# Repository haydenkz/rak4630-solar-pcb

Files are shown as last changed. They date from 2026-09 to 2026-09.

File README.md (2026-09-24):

# rak4630-solar-pcb

Solar-powered MeshCore node PCB built around the **RAK4630-8-SM-I** (nRF52840 + SX1262 LoRa) module.

## Features
- RAK4630-8-SM-I LoRa / MCU module
- Dual-input Li-ion charging (USB-C and solar) via SGM41513 with power-path management
- SMT 18650 battery holder (MYOUNG BH-18650-B1BA002, LCSC C2988620) with NTC temperature sensing
- 3.3 V LDO rail (XC6206P332)
- Hardware low-voltage cutoff (MCP65R41 + TPS22917): switches the node off below ~3.30 V battery and back on above ~3.73 V; no firmware involvement. USB power always overrides it (D3), so the RAK can be flashed over USB with no cell or a flat one. JP1 bypasses it for bench use without USB or a cell.
- SWD programming / test points

## Files
| File | Description |
|---|---|
| `meshcore-solar.kicad_pro` | KiCad project |
| `meshcore-solar.kicad_sch` | Schematic |
| `meshcore-solar.kicad_pcb` | PCB layout |
| `meshcore-solar.pretty/`, `meshcore-solar.3dshapes/` | Project-local footprint (18650 holder) and 3D models |

## Requirements
- KiCad 10 (file format `generator_version 10.0`)
- Symbols and footprints are embedded in the design files. The battery holder footprint and 3D model live in the project library (`meshcore-solar.pretty`, `meshcore-solar.3dshapes`).

## Notes
- Solar panel connects to the PH2.0 `SOLAR IN` connector (P1) → SGM41513 `VAC`.
- No MPPT; the solar input feeds the charger's input-regulation loop directly.

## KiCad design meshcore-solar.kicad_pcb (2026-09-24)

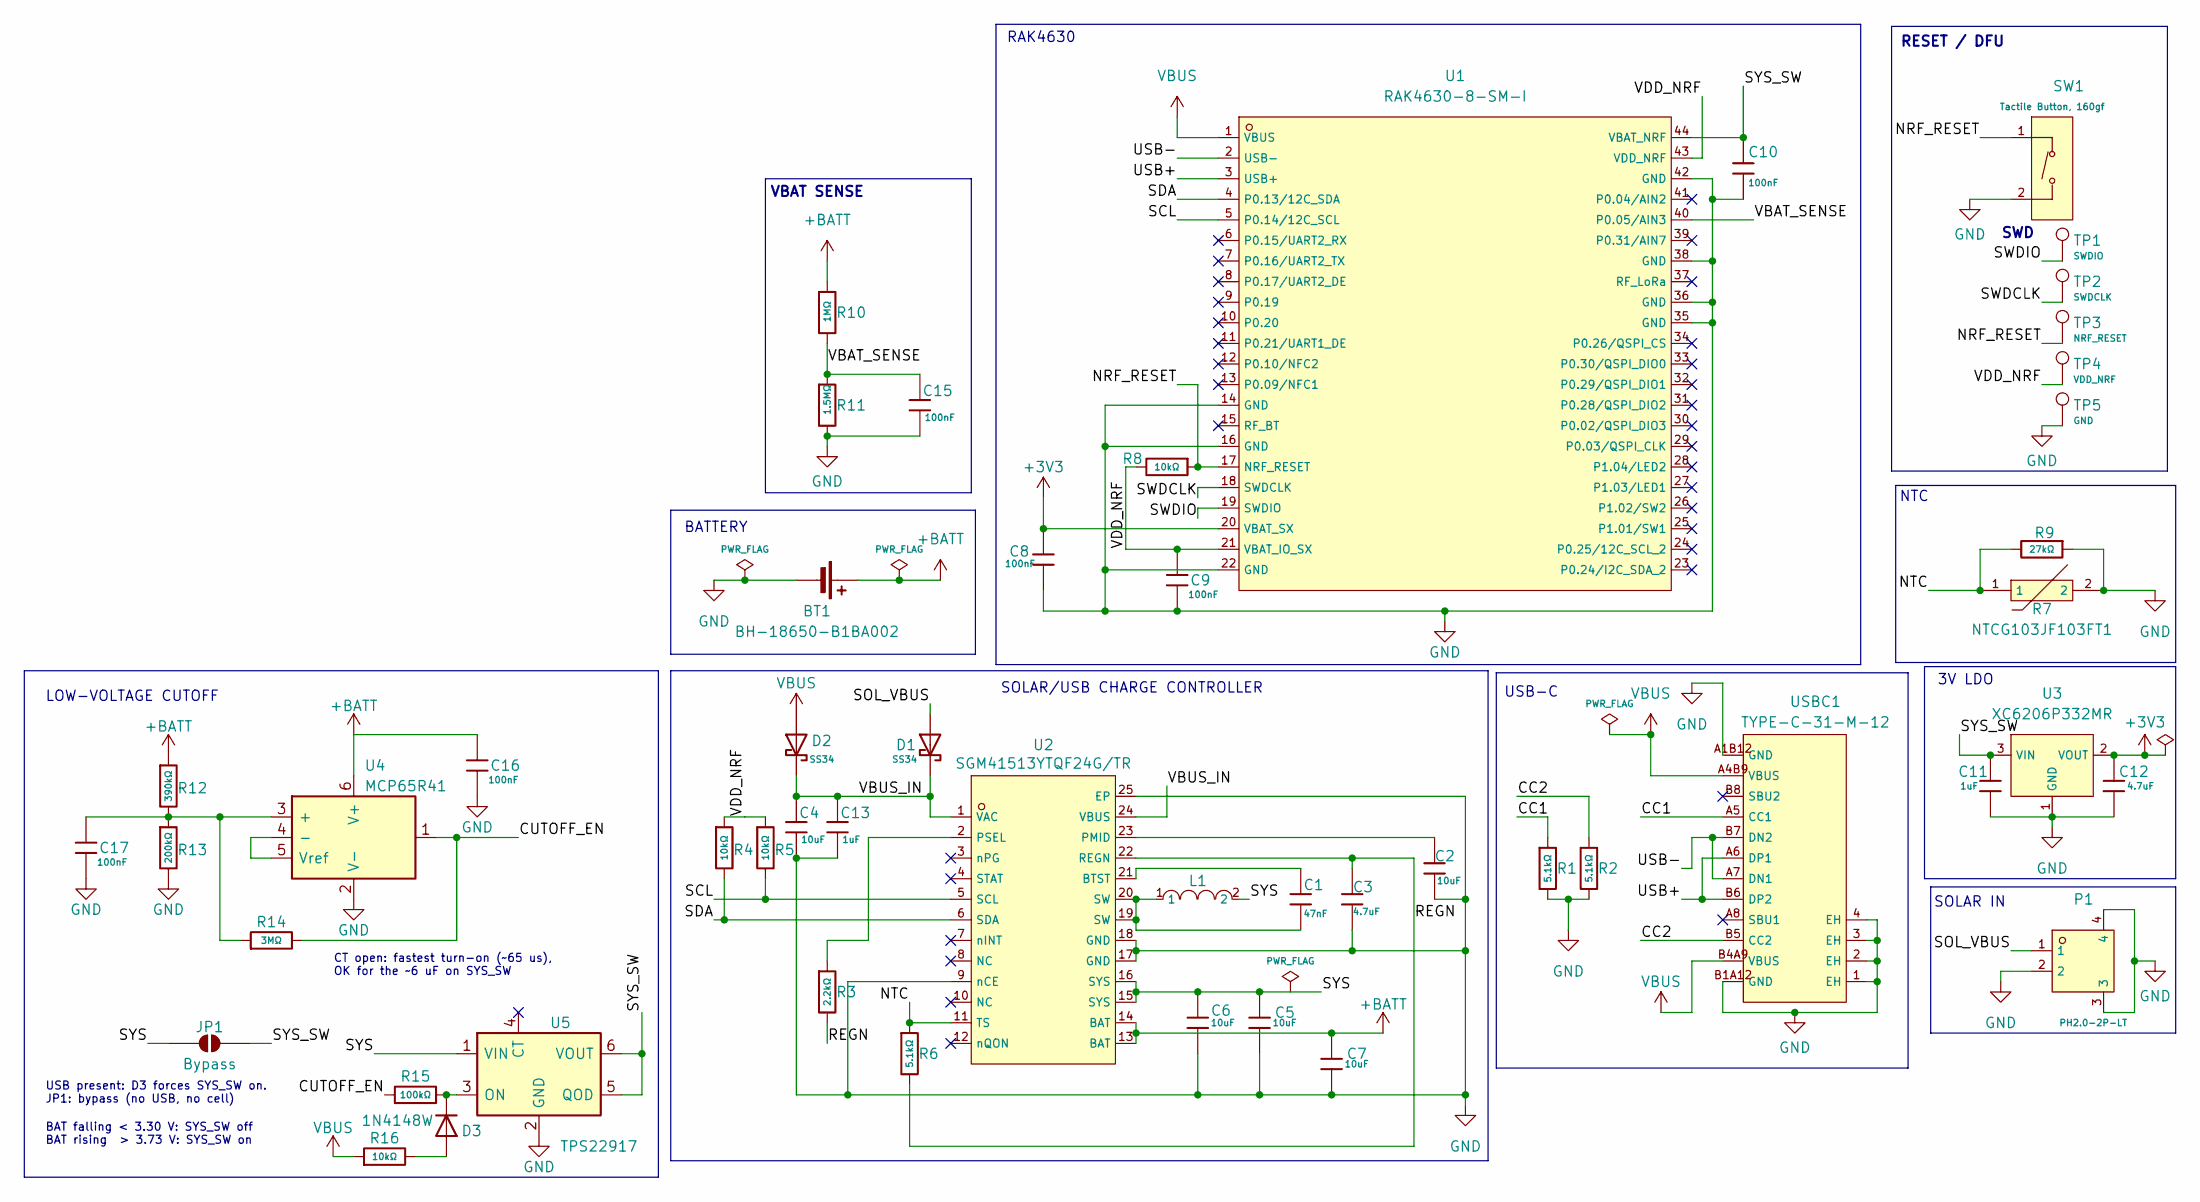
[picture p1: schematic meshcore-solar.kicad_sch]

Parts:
BT1: BH-18650-B1BA002; BatteryHolder_MYOUNG_BH-18650-B1BA002_1x18650; Part BH-18650-B1BA002; LCSC C2988620
C1: 47nF; C_0805; Voltage Rated 50V; Tolerance ±10%; Part CL21B473KBCNNNC; LCSC C53134
C2, C4, C5, C6, C7: 10uF; C_0805; Voltage Rated 25V; Tolerance ±10%; Part CL21A106KAYNNNE; LCSC C15850
C3, C12: 4.7uF; C_0805; Voltage Rated 25V; Tolerance ±10%; Part CL21A475KAQNNNE; LCSC C1779
C8, C9, C10, C15, C16, C17: 100nF; C_0805; Voltage Rated 100V; Tolerance ±10%; Part CL21B104KCFNNNE; LCSC C28233
C11, C13: 1uF; C_0805; Voltage Rated 50V; Tolerance ±10%; Part CL21B105KBFNNNE; LCSC C28323
D1, D2: SS34; D_SMA; Forward Voltage (Vf@If) 550mV@3A; Reverse Voltage (Vr) 40V; Part SS34; LCSC C8678
D3: 1N4148W; D_SOD-123; Part 1N4148W; LCSC C81598
JP1: Bypass; SolderJumper-2_P1.3mm_Open_RoundedPad1.0x1.5mm
L1: FNR3015S1R0MT; C167743_IND-SMD_L3_0-W3_0_FNR30XXS; LCSC C167743
P1: PH2.0-2P-LT; C722761_CONN-SMD_PH2_0-1X2PW; LCSC C722761
R1, R2, R6: 5.1kΩ; R_0805; Overload Voltage (Max) 150V; Tolerance ±1%; Part 0805W8F5101T5E; LCSC C27834
R3: 2.2kΩ; R_0805; Overload Voltage (Max) 150V; Tolerance ±1%; Part 0805W8F2201T5E; LCSC C17520
R4, R5, R8, R16: 10kΩ; R_0805; Overload Voltage (Max) 150V; Tolerance ±1%; Part 0805W8F1002T5E; LCSC C17414
R7: NTCG103JF103FT1; C209959_R0402; LCSC C209959
R9: 27kΩ; R_0805; Overload Voltage (Max) 150V; Tolerance ±1%; Part 0805W8F2702T5E; LCSC C17593
R10: 1MΩ; R_0805; Overload Voltage (Max) 150V; Tolerance ±1%; Part 0805W8F1004T5E; LCSC C17514
R11: 1.5MΩ; R_0805; Overload Voltage (Max) 150V; Tolerance ±1%; Part 0805W8F1504T5E; LCSC C26110
R12: 390kΩ; R_0805; Overload Voltage (Max) 150V; Tolerance ±1%; Part 0805W8F3903T5E; LCSC C17656
R13: 200kΩ; R_0805; Overload Voltage (Max) 150V; Tolerance ±1%; Part 0805W8F2003T5E; LCSC C17539
R14: 3MΩ; R_0805; Overload Voltage (Max) 150V; Tolerance ±1%; Part 0805W8F3004T5E; LCSC C17662
R15: 100kΩ; R_0805; Overload Voltage (Max) 150V; Tolerance ±1%; Part 0805W8F1003T5E; LCSC C149504
SW1: Tactile Button, 160gf; SW_TS-1088-AR02016; Voltage Rating (Dc) 12V; Part TS-1088-AR02016; LCSC C720477
TP1: SWDIO; TestPoint_THTPad_D1.5mm_Drill0.7mm
TP2: SWDCLK; TestPoint_THTPad_D1.5mm_Drill0.7mm
TP3: NRF_RESET; TestPoint_THTPad_D1.5mm_Drill0.7mm
TP4: VDD_NRF; TestPoint_THTPad_D1.5mm_Drill0.7mm
TP5: GND; TestPoint_THTPad_D1.5mm_Drill0.7mm
U1: RAK4630-8-SM-I; C32315253_COMM-SMD_44P-L23_0-W15_0-P1_20_RAK4630-8-SM-I; LCSC C32315253
U2: SGM41513YTQF24G/TR; C5153778_TQFN-24_L4_0-W4_0-P0_50-BL-EP2_6; LCSC C5153778
U3: XC6206P332MR; SOT-23-3_L2.9-W1.6-P1.90-LS2.8-BR; Output Voltage 3.3V; Dropout Voltage 680mV@(100mA); Part XC6206P332MR-G; LCSC C5446
U4: MCP65R41; SOT-23-6; Part MCP65R41T-1202E/CHY; LCSC C219181
U5: TPS22917; SOT-23-6; Part TPS22917DBVR; LCSC C2681320
USBC1: TYPE-C-31-M-12; C165948_USB-C_SMD-TYPE-C-31-M-12_1; LCSC C165948

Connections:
+3V3: C8.1, C12.1, U1.20 (VBAT_SX), U3.2 (VOUT)
+BATT: BT1.1 (+), C7.1, C16.1, R10.1, R12.1, U2.13 (BAT), U2.14 (BAT), U4.6 (V+)
/CC1: R1.1, USBC1.A5 (CC1)
/CC2: R2.1, USBC1.B5 (CC2)
/CUTOFF_EN: R14.2, R15.1, U4.1
/NRF_RESET: R8.1, SW1.1 (A), TP3.1, U1.17 (NRF_RESET)
/NTC: R6.1, R7.1, R9.2, U2.11 (TS)
/REGN: C3.1, R3.2, R6.2, U2.22 (REGN)
/SCL: R5.2, U1.5 (P0.14/12C_SCL), U2.5 (SCL)
/SDA: R4.2, U1.4 (P0.13/12C_SDA), U2.6 (SDA)
/SOL_VBUS: D1.2, P1.1
/SWDCLK: TP2.1, U1.18 (SWDCLK)
/SWDIO: TP1.1, U1.19 (SWDIO)
/SYS: C5.1, C6.1, JP1.1 (A), L1.2, U2.15 (SYS), U2.16 (SYS), U5.1 (VIN)
/SYS_SW: C10.1, C11.1, JP1.2 (B), U1.44 (VBAT_NRF), U3.3 (VIN), U5.5 (QOD), U5.6 (VOUT)
/USB+: U1.3 (USB+), USBC1.A6 (DP1), USBC1.B6 (DP2)
/USB-: U1.2 (USB-), USBC1.A7 (DN1), USBC1.B7 (DN2)
/VBAT_SENSE: C15.1, R10.2, R11.1, U1.40 (P0.05/AIN3)
/VBUS_IN: C4.1, C13.1, D1.1, D2.1, U2.1 (VAC), U2.24 (VBUS)
/VDD_NRF: C9.1, R4.1, R5.1, R8.2, TP4.1, U1.21 (VBAT_IO_SX), U1.43 (VDD_NRF)
GND: BT1.2 (-), C2.1, C3.2, C4.2, C5.2, C6.2, C7.2, C8.2, C9.2, C10.2, C11.2, C12.2, C13.2, C15.2, C16.2, C17.2, P1.2, P1.3, P1.4, R1.2, R2.2, R7.2, R9.1, R11.2, R13.2, SW1.2 (B), TP5.1, U1.14 (GND), U1.16 (GND), U1.22 (GND), U1.35 (GND), U1.36 (GND), U1.38 (GND), U1.42 (GND), U2.9 (nCE), U2.17 (GND), U2.18 (GND), U2.25 (EP), U3.1 (GND), U4.2 (V-), U5.2 (GND), USBC1.1 (EH), USBC1.2 (EH), USBC1.3 (EH), USBC1.4 (EH), USBC1.A1B12 (GND), USBC1.B1A12 (GND); also elsewhere on the board
unnamed: C1.2, L1.1, U2.19 (SW), U2.20 (SW)
unnamed: D3.2 (A), R16.2
unnamed: D3.1 (K), R15.2, U5.3 (ON)
unnamed: C1.1, U2.21 (BTST)
unnamed: C2.2, U2.23 (PMID)
unnamed: R3.1, U2.2 (PSEL)
unnamed: C17.1, R12.2, R13.1, R14.1, U4.3 (+)
unnamed: U4.4 (-), U4.5 (Vref)
VBUS: D2.2, R16.1, U1.1 (VBUS), USBC1.A4B9 (VBUS), USBC1.B4A9 (VBUS)

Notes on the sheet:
USB-C
SOLAR IN
BATTERY
VBAT SENSE
RAK4630
SOLAR/USB CHARGE CONTROLLER
SWD
NTC
RESET / DFU
3V LDO
LOW-VOLTAGE CUTOFF
CT open: fastest turn-on (~65 us), OK for the ~6 uF on SYS_SW
BAT falling < 3.30 V: SYS_SW off BAT rising > 3.73 V: SYS_SW on
USB present: D3 forces SYS_SW on. JP1: bypass (no USB, no cell)

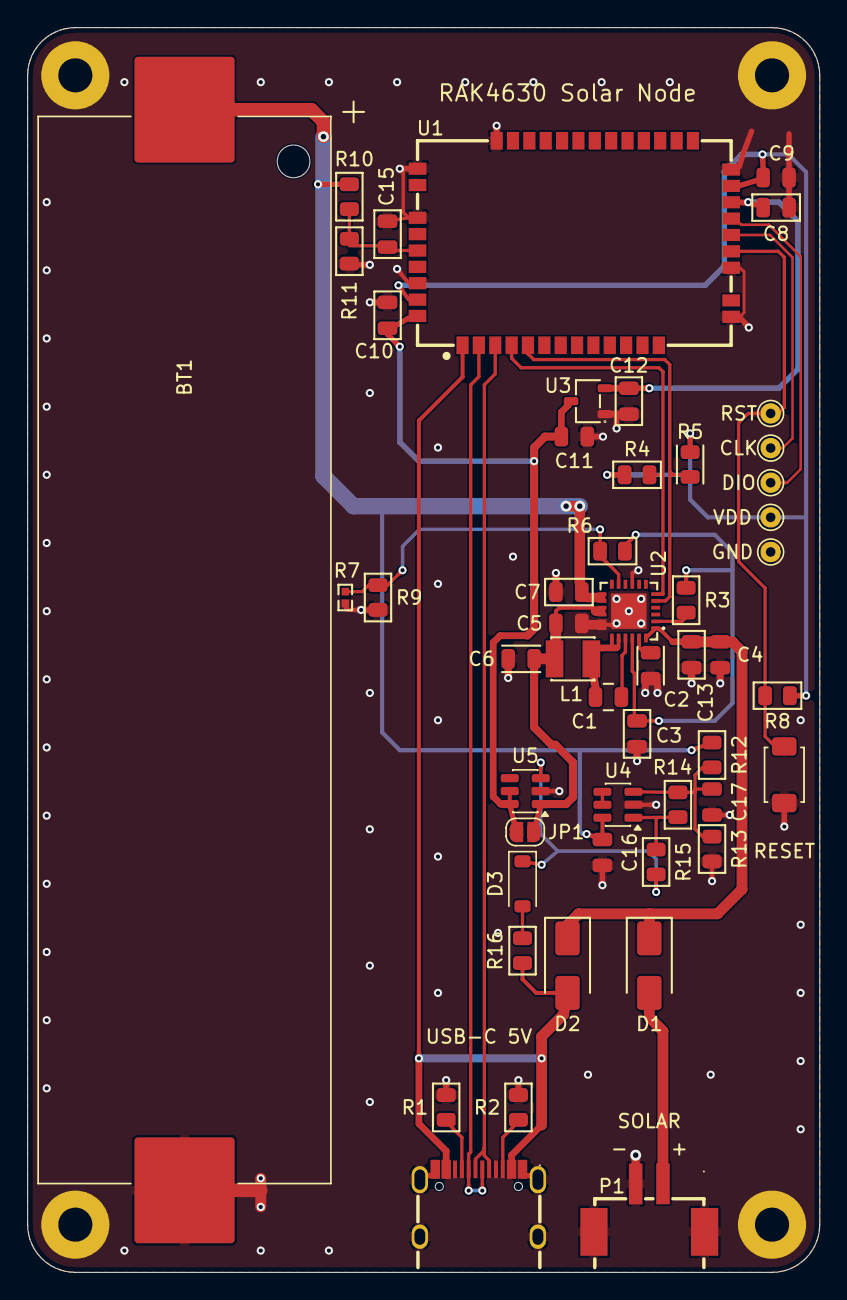
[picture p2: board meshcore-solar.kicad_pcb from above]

Board: 2 copper layers, 58.1 x 91.3 mm, 55 parts (0 on the bottom side), 30 nets.

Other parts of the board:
H1, H2, H3, H4: MountingHole_2.5mm_Pad

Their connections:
GND: H1.1, H2.1, H3.1, H4.1; also elsewhere on the board
